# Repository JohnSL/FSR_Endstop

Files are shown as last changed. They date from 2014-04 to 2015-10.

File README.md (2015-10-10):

FSR_Endstop
===========

Force-Sensitive Resistor controller designed for Delta 3D printers for automatic bed leveling.

## Availability
These circuit boards are now available for purchase from here:

* [Tridprinting.com](http://www.tridprinting.com/Electronics/#3D-Printer-FSR)
* [UltiBots.com](http://www.ultibots.com/fsr-leveling)

You can find my blog post about having these manufactured here: http://trains.socha.com/2014/09/manufacturing-fsr-endstop-controller.html

## History
Back in Februray 2014, Johann modified the Marlin firmware to support force sensitive resistors (FSRs) to allow the firmware to locate the print surface by moving the print nozzle down until the firmware detected that it was touching the bed. FSRs have a very high resistance until you apply pressure, at which point the resistance drops very quickly. You can find more information about his work here: http://reprap.org/wiki/FSR.

I built my own delta printer (http://trains.socha.com/2013/11/building-3dr-simple-delta-printer-part-i.html) and decided to try FSRs. Johann's original branch used one of the thermister inputs, but he later changed to using one of the standard endstop inputs, which I learned when I talked to him at the Seattle Mini Makerfaire. So I tried the endstops.

I had a devel of a time getting it to work. Getting the threshold just right took quite a bit of effort, plus I had to use just the right version of the firmware and get it to load on my Printrboard. It took a little head scratching, and some measurements, to realize that the weight of my glass bed was enough to move the voltage low enough to trigger the end stop. I tried lots of things, and finally used the tape he suggested. That worked better, but I wasn't happy because it was so finiky.

That's how this project got started. I figured it wouldn't be that much effort to use a microcontroller to automatically adjust for the ambient pressure. I'd been wanting to learn how to design and build circuit boards, so my friend Stephen helped me design version 1.0 of this circuit board (in other words, I watched while he layed it out). He also showed me how to hand-solder my first circuit board. You can find more information here:

* [FSR Bed Leveling Trials and Tribulations](http://trains.socha.com/2014/05/fsr-bed-leveling-trials-and-tribulations.html?showComment=1400160705176)
* [Auto Adjust FSR End Stop Detector](http://trains.socha.com/2014/05/auto-adjust-fsr-end-stop-detector.html?showComment=1399251889736)
* [Building the FSR Circuit Boards](http://trains.socha.com/2014/07/building-fsr-circuit-boards.html)

## FSR Endstop Controller
Although not a clever name, it certainly describes what this board does. To use the board, you connect a cable to the endstop on your printer board, and then you connect three FSRs to the inputs of the board. And that's it. The board receives power from the printer board and automatically adjusts to the ambient pressure on the sensors. Whenever the head hits the build plate, the board will detect this and trigger the end stop.

To date, we've made two different versions of the board. Revision 1.1 is shown on the left, and 1.2 is on the right:

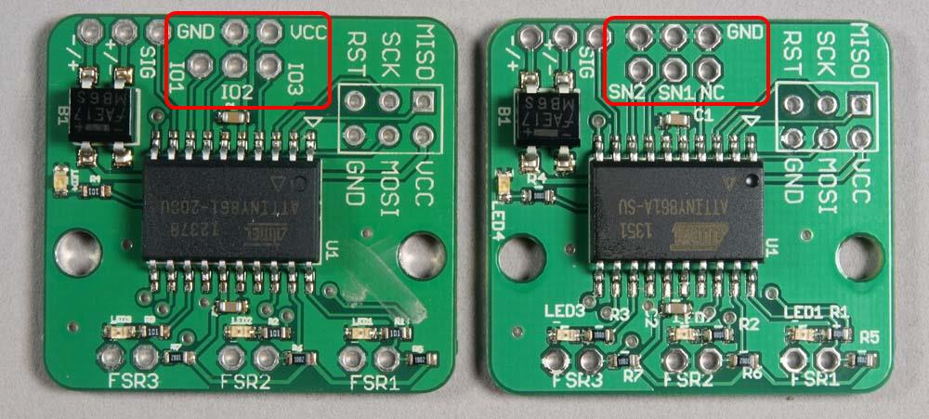
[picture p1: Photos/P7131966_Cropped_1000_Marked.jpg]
Board Versions


The difference between these two is the arrangement of pins that can be used to modify the behavior of the board. In the revision 1.1 board, these pins are labeld IO1, IO2, and IO3. While the same pins are labeled SN2, SN1, and NC on the revision 1.2 boards. Additionally, the 1.2 boards allow you to solder in a 2 by 3 array of header pins and then use jumpers to connect any combination of these three pins to ground (GND), whereas the 1.1 boards require using wires to connect any combination of these pins to GND.

### Wiring the Endstop
Use a three-wire cable to connect the endstop on your printer board to this circuit board. These should be connected to the three pins labeled "+/-", "+/-", and "SIG" in the upper-left corner of the image above. On all the printer boards I've looked at, the signal wire is on the outside. The 5V connection is either on the middle pin or the outside pin. You'll want to check your printer board to ensure you attach the connector with the correct orientation.

### Setting the Sensitivity
There are two jumpers  you can use to modify the sensitivy of this board. By default (no jumpers), the force much be such that the voltage drops below 0.92 of the ambient value before the output is triggered. Each FSR is monitored independently of the others, so the output will trigger when at least one FSR triggers an input. In the table below, GND means you've connected that pin to ground.

| SN1 / IO2 | SN2 / IO1 | Sensitivity |
|---|---|---|
| GND | GND | 0.8 |
| GND |  -  | 0.85 |
|  -  | GND | 0.95 |
|  -  |  -  | 0.92 |

### Setting NC/NO Behavior
By default, the end stop output will be normally open (NO), which should work fine with any printer. However if you want to change this to normally closed (NC), connect pin NC/IO3 to GND.

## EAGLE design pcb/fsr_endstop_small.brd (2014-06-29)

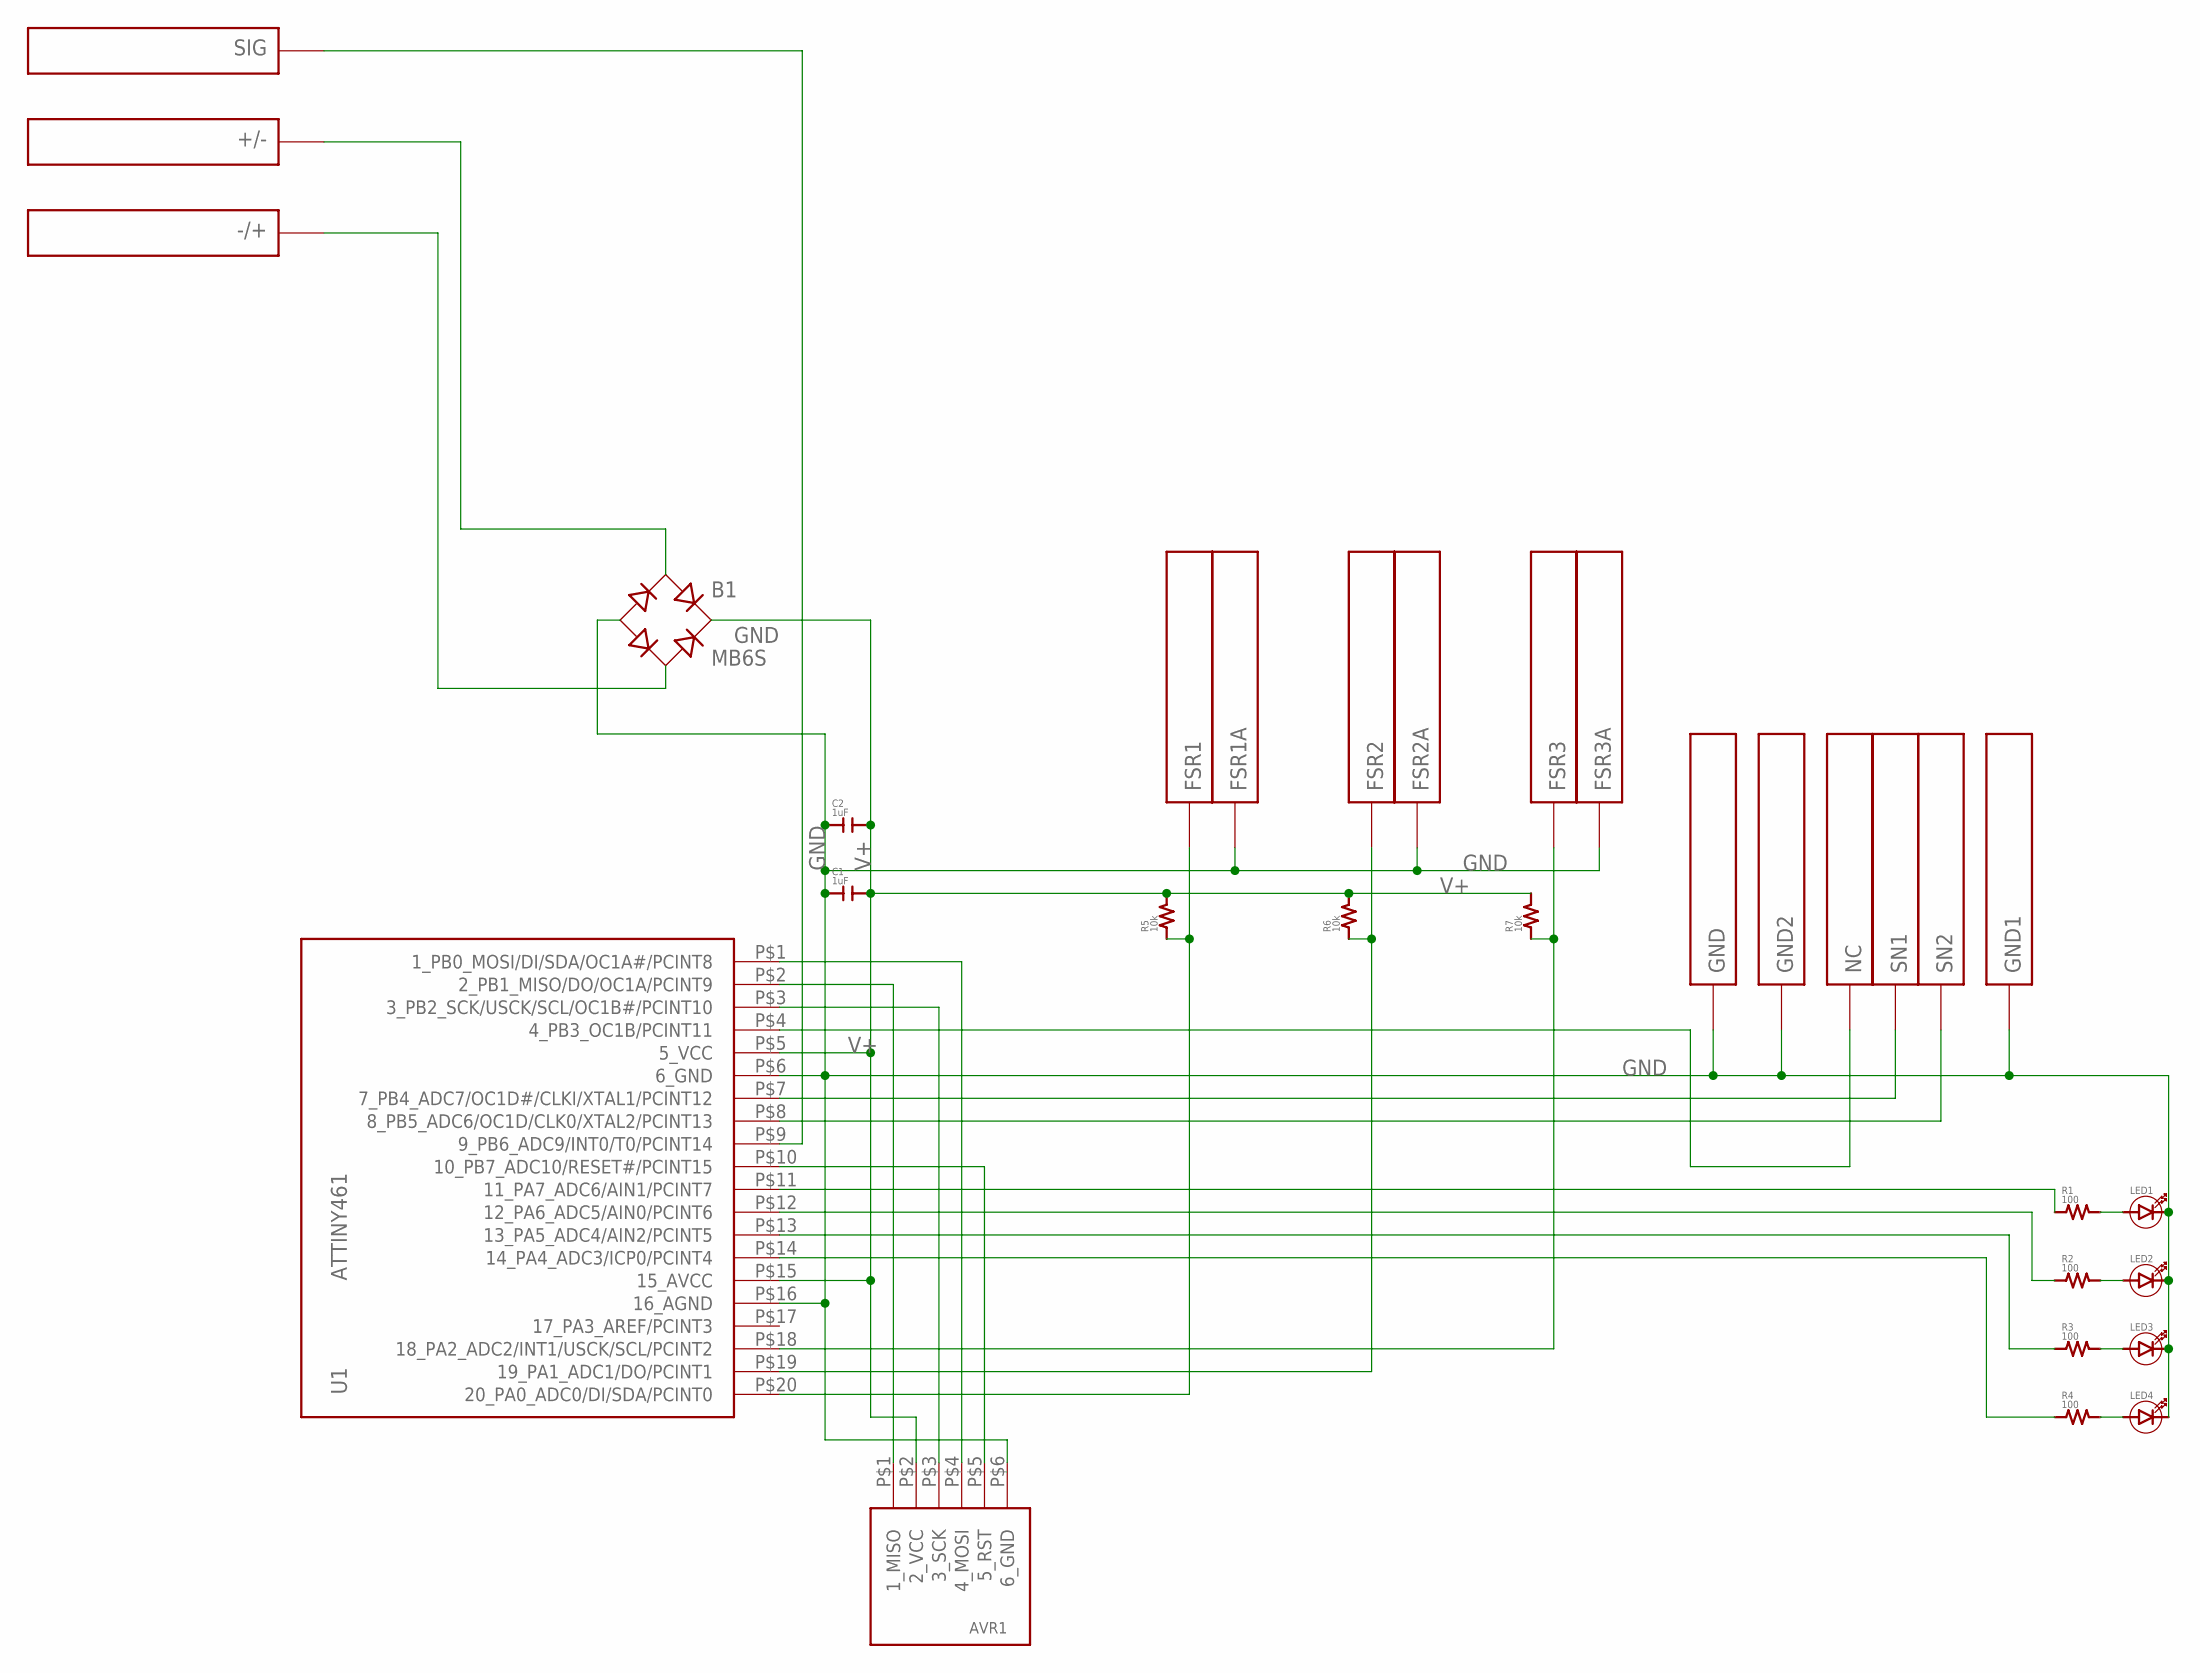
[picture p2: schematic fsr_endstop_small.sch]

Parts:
+/-: PIN1.2MM; PIN_1.2MM
-/+: PIN1.2MM; PIN_1.2MM
AVR1: AVR6
B1: MB6S; SOIC-4
C1, C2: 1uF; 0603
FSR1, FSR1A, FSR2, FSR2A, FSR3, FSR3A: PIN1.2MM; PIN_1.2MM
GND, GND1, GND2: PIN1.2MM; PIN_1.2MM
LED1, LED2, LED3, LED4: LED0603; 0603_DIODE
NC: PIN1.2MM; PIN_1.2MM
R1, R2, R3, R4: 100; 0603
R5, R6, R7: 10k; 0603
SIG: PIN1.2MM; PIN_1.2MM
SN1, SN2: PIN1.2MM; PIN_1.2MM
U1: ATTINY461; SOIC-20

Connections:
GND: AVR1.P$6 (6_GND), B1.-, C1.1, C2.1, FSR1A.P$1, FSR2A.P$1, FSR3A.P$1, GND.P$1, GND1.P$1, GND2.P$1, LED1.-, LED2.-, LED3.-, LED4.-, U1.P$6 (6_GND), U1.P$16 (16_AGND)
unnamed: AVR1.P$4 (4_MOSI), U1.P$1 (1_PB0_MOSI/DI/SDA/OC1A#/PCINT8)
unnamed: AVR1.P$1 (1_MISO), U1.P$2 (2_PB1_MISO/DO/OC1A/PCINT9)
unnamed: -/+.P$1, B1.~2 (AC2)
unnamed: +/-.P$1, B1.~1 (AC1)
unnamed: AVR1.P$3 (3_SCK), U1.P$3 (3_PB2_SCK/USCK/SCL/OC1B#/PCINT10)
unnamed: AVR1.P$5 (5_RST), U1.P$10 (10_PB7_ADC10/RESET#/PCINT15)
unnamed: FSR1.P$1, R5.1, U1.P$20 (20_PA0_ADC0/DI/SDA/PCINT0)
unnamed: FSR2.P$1, R6.1, U1.P$19 (19_PA1_ADC1/DO/PCINT1)
unnamed: FSR3.P$1, R7.1, U1.P$18 (18_PA2_ADC2/INT1/USCK/SCL/PCINT2)
unnamed: R4.1, U1.P$14 (14_PA4_ADC3/ICP0/PCINT4)
unnamed: R3.1, U1.P$13 (13_PA5_ADC4/AIN2/PCINT5)
unnamed: R2.1, U1.P$12 (12_PA6_ADC5/AIN0/PCINT6)
unnamed: R1.1, U1.P$11 (11_PA7_ADC6/AIN1/PCINT7)
unnamed: SIG.P$1, U1.P$9 (9_PB6_ADC9/INT0/T0/PCINT14)
unnamed: NC.P$1, U1.P$4 (4_PB3_OC1B/PCINT11)
unnamed: SN2.P$1, U1.P$8 (8_PB5_ADC6/OC1D/CLK0/XTAL2/PCINT13)
unnamed: SN1.P$1, U1.P$7 (7_PB4_ADC7/OC1D#/CLKI/XTAL1/PCINT12)
unnamed: LED1.+, R1.2
unnamed: LED2.+, R2.2
unnamed: LED3.+, R3.2
unnamed: LED4.+, R4.2
V+: AVR1.P$2 (2_VCC), B1.+, C1.2, C2.2, R5.2, R6.2, R7.2, U1.P$5 (5_VCC), U1.P$15 (15_AVCC)

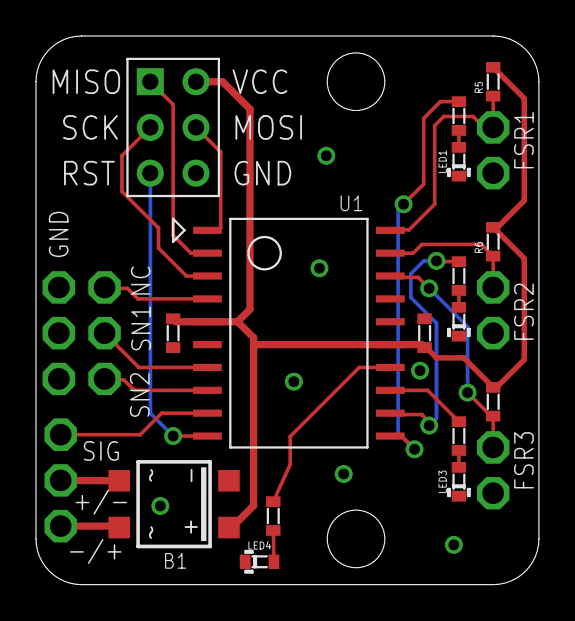
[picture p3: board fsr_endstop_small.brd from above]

Board: 2 copper layers, 27.9 x 30.5 mm, 32 parts (1 on the bottom side), 23 nets.

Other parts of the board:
U$1: OSHW-LOGO-M

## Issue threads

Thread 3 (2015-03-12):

Raw FSR values over SPI?

626Pilot, 2015-03-12:
Hi. I'm working on an AI delta printer calibration fork of Smoothieware. It works really well so far, but only knowing the depth (not X and Y) limits accuracy. It has to assume the probe is hitting at the X and Y where it thinks it is, because it has no actual feedback other than depth.

I have a theory that FSRs might be used to triangulate the X and Y position being touched. I don't know if FSRs have enough accuracy or repeatability, but if they do, it would be great. I ordered one of your boards recently and I'd like to try to get it talking to a Smoothieboard controller over SPI. I know the processor supports that protocol. Do you think the processor is fast enough, and has enough RAM, to continuously stream the FSR values over SPI? I wouldn't have it maintain a running average or anything like that - just have it send numbers over the wire.

JohnSL, 2015-03-14:
Yes, it should not be a problem to use SPI to send data to a Smoothieboard. Did you want the FSR controller to be the SPI slave or master?

626Pilot, 2015-03-14:
I suppose it would be a slave. Given your experience writing the firmware, do you think typical FSRs have enough accuracy/repeatability to triangulate a position to better than 0.04mm? That would be the minimum useful resolution.

JohnSL, 2015-03-15:
Making a slave would be really easy, so I'll work on getting a version of the firmware that supports SPI. As to accuracy, I think it depends on the machine and speeds involved. The sensor itself doesn't really change in thickness enough to be an issue.

It seems like we should move this discussion to a forum somewhere. If you send me a link of a good place to continue the discussion, I'll move over there.

626Pilot, 2015-03-17:
Alright, that makes sense to me. I'd like to invite you to join the SeeMeCNC forums, where some of our members are already using your endstop board. I've posted a thread here: http://forum.seemecnc.com/viewtopic.php?f=82&t=7936

626Pilot, 2015-03-22:
This idea is dead. The pressure gradient is too small to measure with even poor accuracy, and would be disturbed to the point of unusability by the tiniest environmental disturbance (stepper motor vibrations, someone sneezed two blocks away, etc.)

Closed 2015-03-22.

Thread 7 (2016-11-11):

using the board with external 5v source

paboman, 2016-11-11:
Hi,
I would like to use this board with an external 5v source, then somehow connect it to the 2 pins of the z probe input on my printer.
is that possible?

ps
I cant use 5v directly from the printer, thats why im asking
rgds
PB

ianlee74, 2016-11-11:
That will work fine. You just need to also connect the grounds between your power supply and your printer.

paboman, 2016-11-12:
i want to use a power bank for the 5v.
so connecting the printer metal frame to the  the powerbank gnd will work ?
but the gnd of the power bank is the metal case of the usb plug or the black wire?
thx again

ianlee74, 2016-11-12:
I wouldn't depend on the case being a good ground. You should be able to find a ground wire from your controller's power supply or a ground pin on the controller itself that you can connect the JohnSL board to.

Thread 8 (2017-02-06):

Controller should detect bad/flakey FSR connection

jonkean, 2017-02-06:
After tracking down why my bed was never leveling quite right, I found one of my FSR sensors was damaged (small crack running across a surface wire on one sensor).  It would sometimes make a connection, other times not.  When the connection was broken, the FSR controller would not detect pressure and it would not give an error.

Is the controller sensitive enough to distinguish between an FSR with zero pressure (ie: MΩ resistance), and between no connection at all (ie: a damaged or disconnected sensor with infinite resistance)?

If the controller is not sensitive enough, a small fixed resistor could be added parallel to each FSR sensor, and then the controller could detect a bad connection by checking for a resistance under value N.  This would require a PCB change, or could be retrofitted by adding the resistors to each FSR sensor wiring.

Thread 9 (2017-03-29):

Use on a square Cartesian bed.

mshievitz, 2017-03-29:
So far the best way I can figure to do this is using the 3 fsr pads under the bed using a maximum equilateral triangle solution or just inside the leveling screws one in each corner and one mid bed on the opposite edge...
It would be nice to be able to attach a 4th fsr and place them in each corner to reduce any possible cantilevered error due to areas probed outside a triangle within the square bed.

Is there a way to do this? Or should I just restrict the probe points to areas directly over the 3 sensors?

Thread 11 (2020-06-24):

False Triggering

inventabuild, 2020-06-24:
I have four fsr's set up on a flat surface w/ a flat glass plate on top of them and I'm running 2 sets of 2 ea fsr connected in parallel or a total of 4 ea frs.  The resistance I measured in the wires attached to the fsr's ranges from 160K to 240K ohms.

1. Do I need to lower the sensitivity of JohnSL board to prevent false triggers?
2. Can I add  500K ohm resistor in series with the fsr's to help prevent false triggers?

Please advise.  Thank you.

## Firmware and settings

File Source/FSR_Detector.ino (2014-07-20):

// Pin layout copied from pins.arduino.h for convience, and then added how the pins are
// connected on the circuit board.
//
// ATMEL ATTINY861
//
//                             +-\/-+
// MOSI           (D  9) PB0  1|    |20  PA0 (D  0)           FSR1
// MISO          *(D  8) PB1  2|    |19  PA1 (D  1)           FSR2
// SCK            (D  7) PB2  3|    |18  PA2 (D  2) INT1      FSR3
// NC/IO3        *(D  6) PB3  4|    |17  PA3 (D 14)
//                       VCC  5|    |16  AGND
//                       GND  6|    |15  AVCC
// SN1/IO2        (D  5) PB4  7|    |14  PA4 (D 10)           LED4
// SN2/IO1       *(D  4) PB5  8|    |13  PA5 (D 11)           LED3
// SIG       INT0 (D  3) PB6  9|    |12  PA6 (D 12)           LED2
// RST            (D 15) PB7 10|    |11  PA7 (D 13)           LED1
//                             +----+
//

#define VERSION     1

// Define the pins that have LEDs on them. We have one LED for each of the three FSRs to indicate
// when each FSR is triggered. And one power/end stop LED that is on until any of the FSRs are
// triggered.
#define LED1        13
#define LED2        12
#define LED3        11

#define LEDTRIGGER  10
#define ENDSTOP     3

// Define the pins used for the analog inputs that have the FSRs attached. These have external
// 10K pull-up resistors.
#define FSR1        A0
#define FSR2        A1
#define FSR3        A2

// Jumper pins, which are labels IO3, IO2, and IO1 on the revision 1.1 boards. On the
// revision 1.2 boards, these are labeled NC, SN1, and SN2
#define NC_PIN      6
#define SEN1        5
#define SEN2        4

// The end stop output
#define TRIGGER     03
#define TRIGGERED   LOW
#define UNTRIGGERED HIGH

//  SEN1    SEN2    Threshold
//  ----    ----    ---------
//   0       0          0.80
//   0       1          0.85
//   1       0          0.95
//   1       1          0.92
const float thresholds[] = { 0.80, 0.85, 0.95, 0.92 };

short fsrLeds[] = { LED1, LED2, LED3 };     // Pins for each of the LEDs next to the FSR inputs
short fsrPins[] = { FSR1, FSR2, FSR3 };     // Pins for each of the FSR analog inputs

#define SHORT_SIZE 8
#define LONG_SIZE 16
#define LONG_INTERVAL (2000 / LONG_SIZE)

unsigned long lastLongTime[3];              // Last time in millis that we captured a long-term sample
uint16_t longSamples[3][LONG_SIZE];         // Used to keep a long-term average
uint8_t longIndex[3] = {0, 0, 0};           // Index of the last long-term sample
uint16_t longAverage[3] = {0, 0, 0};

uint16_t shortSamples[3][SHORT_SIZE];       // Used to create an average of the most recent samples
uint8_t averageIndex[3] = {0, 0, 0};

//
// Set the triggered state based on the state of one FSR
//
void SetOutput(short fsr, bool state)
{
    static bool triggered[3] = {false};     // Keeps track of current FSR trigger state, initiall not triggered

    // Turns on the FSR LED when that FSR is triggered
    triggered[fsr] = state;
    digitalWrite(fsrLeds[fsr], state ? HIGH : LOW);

    // See if any of the FSRs are currently triggered
    bool any = false;
    for (uint8_t fsr = 0; fsr < 3; fsr++)
    {
        any |= triggered[fsr];
    }

    digitalWrite(LEDTRIGGER, any ? LOW : HIGH);

    // For the end stop, we need to check the NC jumpper to see if we need to invert
    // the output.
    int ncPin = digitalRead(NC_PIN);
    if (ncPin == 1)
    {
        // No jumper installed, so use Normally Closed
        digitalWrite(ENDSTOP, any ? LOW : HIGH);
    }
    else
    {
        // Jumper installed, so use Normally Open
        digitalWrite(ENDSTOP, any ? HIGH: LOW);
    }
}

void InitValues()
{
    for (uint8_t fsr = 0; fsr < 3; fsr++)
    {
        for (uint8_t i = 0; i < SHORT_SIZE; i++)
            shortSamples[fsr][i] = 0;

        for (uint8_t i = 0; i < LONG_SIZE; i++)
            longSamples[fsr][i] = 0;
    }

    for (uint8_t fsr = 0; fsr < 3; fsr++)
        lastLongTime[fsr] = millis();
}

void InitializeJumpers()
{
    pinMode(NC_PIN, INPUT_PULLUP);
    pinMode(SEN1, INPUT_PULLUP);
    pinMode(SEN2, INPUT_PULLUP);
}

//
// Briefly turns on FSR LEDs during startup to indicate the version number of the
// firmware.
//
void BlinkVersion(uint8_t version)
{
    for (uint8_t i = 0; i < 3; i++)
    {
        digitalWrite(fsrLeds[i], (version & (1 << i)) ? HIGH : LOW);
    }
    delay(250);
    for (uint8_t i = 0; i < 3; i++)
    {
        digitalWrite(fsrLeds[i], LOW);
    }
}

//
// One-time setup for the various I/O ports
//
void setup()
{
    InitValues();

    for (uint8_t fsr = 0; fsr < 3; fsr++)
    {
        // Set the FSR LEDs for output and turn them off
        uint8_t pin = fsrLeds[fsr];
        pinMode(pin, OUTPUT);
        digitalWrite(pin, LOW);

        // Set the FSR lines for inputs without a pull-up since the board has external 10K
        // pull-up resistors.
        pin = fsrPins[fsr];
        pinMode(pin, INPUT);
    }

    // Set the green combined LED to on so it acts as a power-on indicator. We'll turn it
    // off whenever we trigger the end stop.
    pinMode(LEDTRIGGER, OUTPUT);
    digitalWrite(LEDTRIGGER, HIGH);

    // Set the endstop pin to be an output that is set for NC
    pinMode(ENDSTOP, OUTPUT);

    // Set the jumpers to use the internal pull-up resiter and be for input
    InitializeJumpers();

    BlinkVersion(VERSION);
};

//
// Captures a new value once LONG_INTERVAL ms have passed since the last sample.
//
// Returns: The current long-range average
uint16_t UpdateLongSamples(short fsr, int avg)
{
    //
    // If enough time hasn't passed, just return the last value
    //
    unsigned long current = millis();
    if (current - lastLongTime[fsr] <= LONG_INTERVAL)
    {
        return longAverage[fsr];
    }

    //
    // Update the log sample with the new value, and then update the long average
    //
    longSamples[fsr][longIndex[fsr]++] = avg;
    if (longIndex[fsr] >= LONG_SIZE)
    {
        longIndex[fsr] = 0;
    }

    uint16_t total = 0;
    for (int i = 0; i < LONG_SIZE; i++)
    {
        total += longSamples[fsr][i];
    }
    
    longAverage[fsr] = total / LONG_SIZE;

    lastLongTime[fsr] = millis();
    return longAverage[fsr];
}

//
// Returns the current threshold to use, baed on jumpers installed
//
inline float GetThreshold()
{
    int sen1 = digitalRead(SEN1);
    int sen2 = digitalRead(SEN2);

    int index = sen1 << 1 | sen2;
    return thresholds[index];
}

//
// This method is called after every sample to see if the output trigger status should be changed.
// It will also the short sample buffer, and it may update the long-term samples.
//
void CheckIfTriggered(short fsr)
{
    //
    // Calculate the average of the most recent short-term samples
    //
    uint16_t total = 0;
    for (int i = 0; i < SHORT_SIZE; i++)
    {
        total += shortSamples[fsr][i];
    }
    uint16_t avg = total / SHORT_SIZE;

    uint16_t longAverage = UpdateLongSamples(fsr, avg);

    uint16_t threshold = GetThreshold() * longAverage;

    bool triggered = avg < threshold;
    SetOutput(fsr, triggered);
}

void loop()
{
    for (uint8_t fsr = 0; fsr < 3; fsr++)
    {
        int value = analogRead(fsrPins[fsr]);

        shortSamples[fsr][averageIndex[fsr]++] = value;
        if (averageIndex[fsr] >= SHORT_SIZE)
        {
            averageIndex[fsr] = 0;
        }
        CheckIfTriggered(fsr);
    }
};

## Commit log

2014-04-06 Initial schematic commit
    [fsr_endstop.sch]
2014-04-06 Schematic first rev complete
    [fsr_endstop.sch]
2014-04-06 Finished first component placement
    [fsr_endstop.brd]
2014-04-06 Packed components in tighter
    [fsr_endstop.brd]
2014-04-06 Completed routing
    [fsr_endstop.brd, fsr_endstop.sch]
2014-04-06 Added ground plane, final 1 layer board.
    [fsr_endstop.brd]
2014-04-06 Initial component placement for smaller 2-layer board
    [fsr_endstop_small.brd, fsr_endstop_small.sch]
2014-04-06 Completed non-GND routing
    [fsr_endstop_small.brd]
2014-04-06 Added ground plane, done with small version
    [fsr_endstop_small.brd]
2014-04-06 Cleanedup silkscreen, added board name to back
    [fsr_endstop_small.brd]
2014-04-08 Moving PCB design files to subdirectory
    [fsr_endstop.brd, fsr_endstop.sch, fsr_endstop_small.brd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]
2014-04-27 Fixed problem with FSR3 staying triggered.
    [FSR_Detector.ino]
2014-04-27 Added tiggered LED support
2014-04-28 Reverse polarity of diodes
    Diodes were backwards in the schematic for the bridge rectifier.
    [fsr_endstop.brd, fsr_endstop.sch, fsr_endstop_small.brd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]
2014-05-03 Adding missing trace between LED4 and R4
    [fsr_endstop_small.brd]
2014-05-03 Replaced the discrete diodes with a bridge rectifier chip for easier hand soldering.
    [fsr_endstop_small.brd, fsr_endstop_small.sch]
2014-05-13 Made various fixes to the 1.1 version.
    [fsr_endstop_small.brd]
2014-06-16 After sending to DFRobot, using their design rules file.
    [fsr_endstop_small.brd]
2014-06-29 Revision 1.2 includes three jumpers for modifying settings.
    [fsr_endstop_small.brd, fsr_endstop_small.sch]
2014-07-13 Moved the trigger check outside of the short sample loop so the variance in trigger times will be less, and triggers will be faster, on average.
    [FSR_Detector.ino]
2014-07-13 The first version of the firmware on shipping boards.
2014-07-13 This version has improved reaction time as a result of moving the trigger checkout outside of the loop used to upate the short sample array.
2014-07-20 Now blink the red LEDs during startup to indicate the firmware version

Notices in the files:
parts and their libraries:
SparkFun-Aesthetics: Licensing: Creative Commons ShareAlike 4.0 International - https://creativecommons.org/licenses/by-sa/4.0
